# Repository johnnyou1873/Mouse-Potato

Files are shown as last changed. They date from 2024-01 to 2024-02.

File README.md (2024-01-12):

# Mouse-Potato
Micromouse design for AAMC 2024

## Major Components

### Microcontroller
STMicroelectronics STM32F411RETx

### Motors
*2x* CHF-GW12T-N20VA ABHL DC Worm Gear Motor
- Ratio: 42-A
- Voltage: 6V B45
- https://www.aliexpress.us/item/3256801422029348.html
- Requires shortening of the encoder board and resoldering of the cables

### Motor Driver
STMicroelectronics L293DD

### IMU
TDK InvenSense ICM-42688-P

### ToF Sensors
*3x* Adafruit VL6180X Time of Flight Micro-LIDAR Distance Sensor Breakout

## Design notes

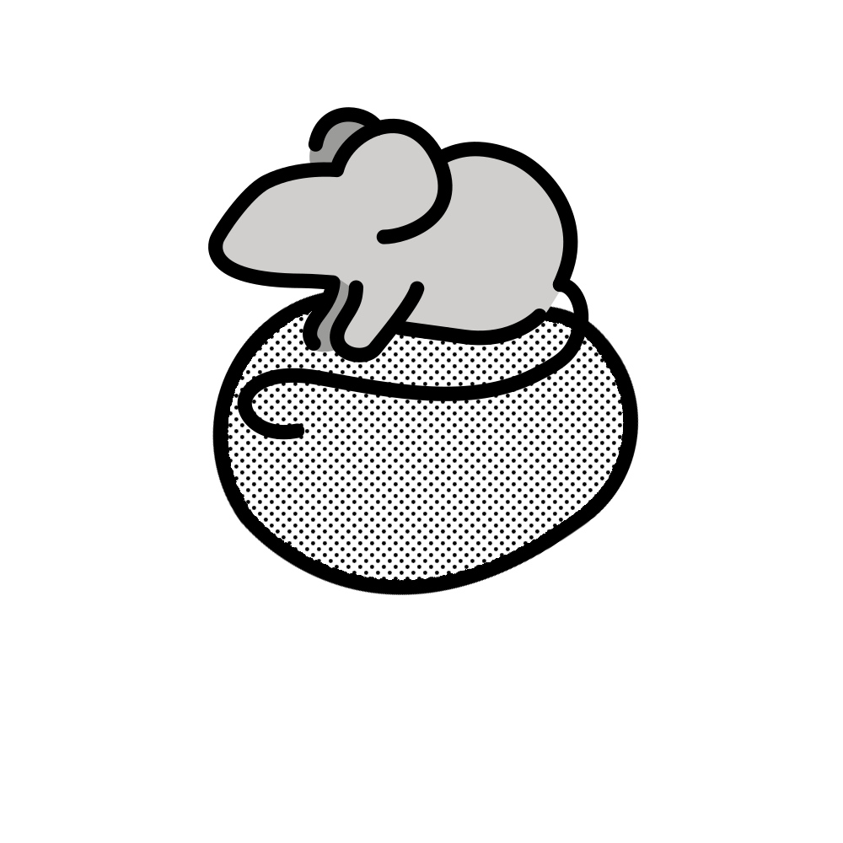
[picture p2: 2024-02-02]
art/mouse_potato.png

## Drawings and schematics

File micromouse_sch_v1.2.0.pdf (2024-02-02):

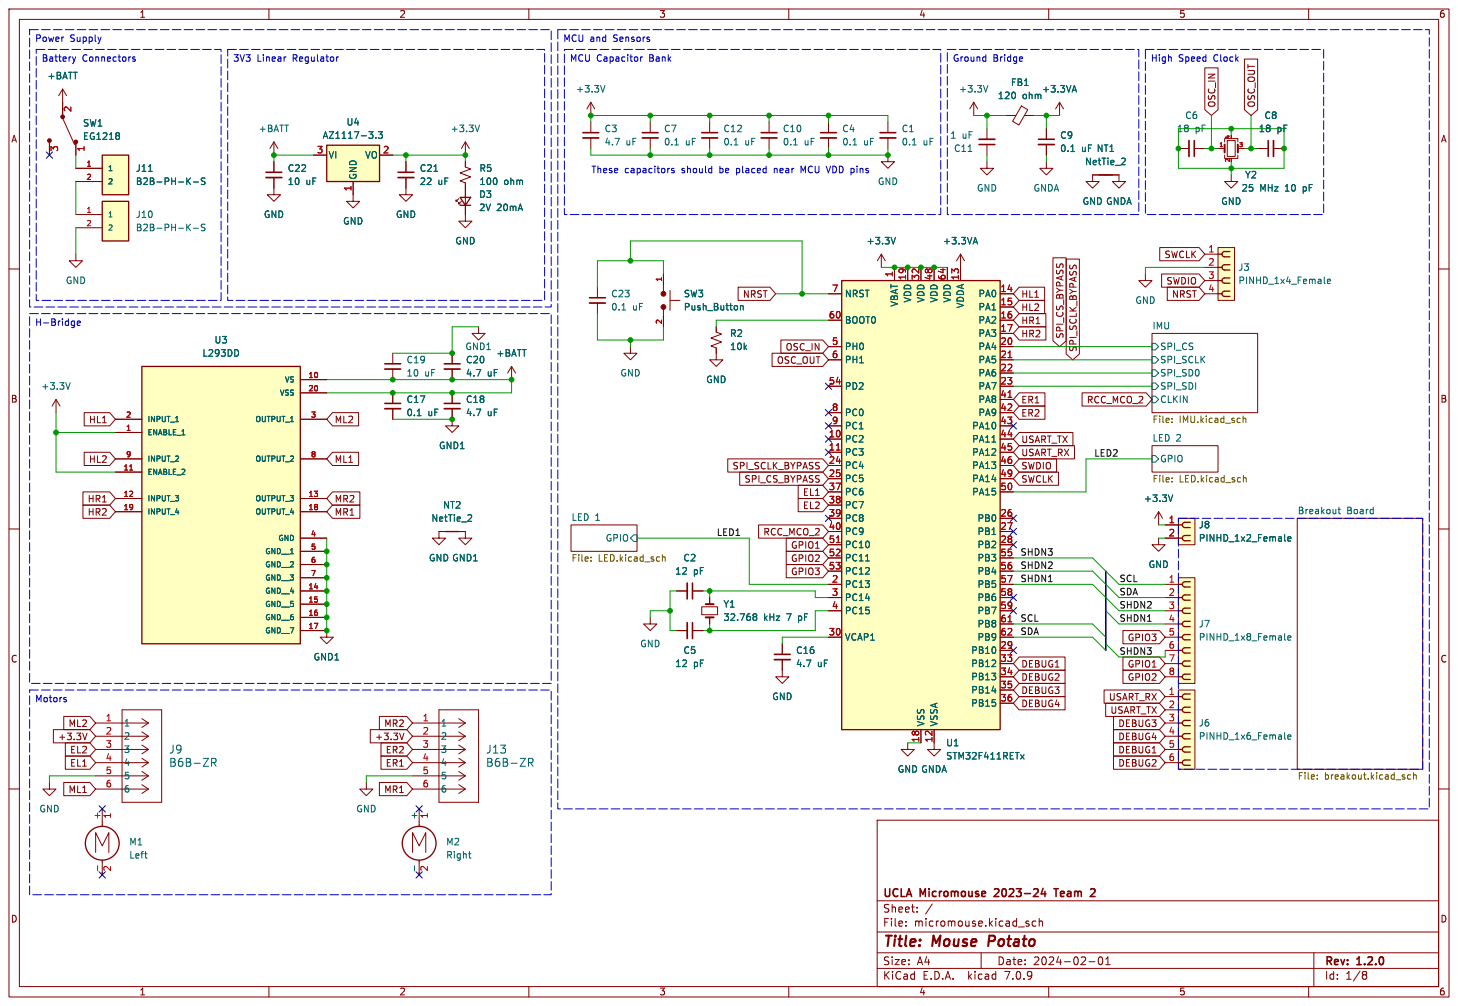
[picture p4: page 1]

1 VO 2 VI 3 U4 AZ1117-3.3 GND GND
+BATT GND

1 VO 2 VI 3 GND GND

1 PC2 10 PC3 11 VSSA 12 VDDA 13 PA0 14 PA1 15 PA2 16 PA3 17 VSS 18 VDD 19 PC13 2 PA4 20 PA5 21 PA6 22 PA7 23 PC4 24 PC5 25 PB0 26 PB1 27 PB2 28 PB10 29 PC14 3 VCAP1 30 VDD 32 PB12 33 PB13 34 PB14 35 PB15 36 PC6 37 PC7 38 PC8 39 PC15 4 PC9 40 PA8 41 PA9 42 PA10 43 PA11 44 PA12 45 PA13 46 VDD 48 PA14 49 PH0 5 PA15 50 PC10 51 PC11 52 PC12 53 PD2 54 PB3 55 PB4 56 PB5 57 PB6 58 PB7 59 PH1 6 BOOT0 60 PB8 61 PB9 62 VDD 64 NRST 7 PC0 8 PC1 9 U1STM32F411RETx GND

1 PC2 10 PC3 11 VSSA 12 VDDA 13 PA0 14 PA1 15 PA2 16 PA3 17 VSS 18 VDD 19 PC13 2 PA4 20 PA5 21 PA6 22 PA7 23 PC4 24 PC5 25 PB0 26 PB1 27 PB2 28 PB10 29 PC14 3 VCAP1 30 VDD 32 PB12 33 PB13 34 PB14 35 PB15 36 PC6 37 PC7 38 PC8 39 PC15 4 PC9 40 PA8 41 PA9 42 PA10 43 PA11 44 PA12 45 PA13 46 VDD 48 PA14 49 PH0 5 PA15 50 PC10 51 PC11 52 PC12 53 PD2 54 PB3 55 PB4 56 PB5 57 PB6 58 PB7 59 PH1 6 BOOT0 60 PB8 61 PB9 62 VDD 64 NRST 7 PC0 8 PC1 9 GND

Id: 1/8 Title: Mouse Potato

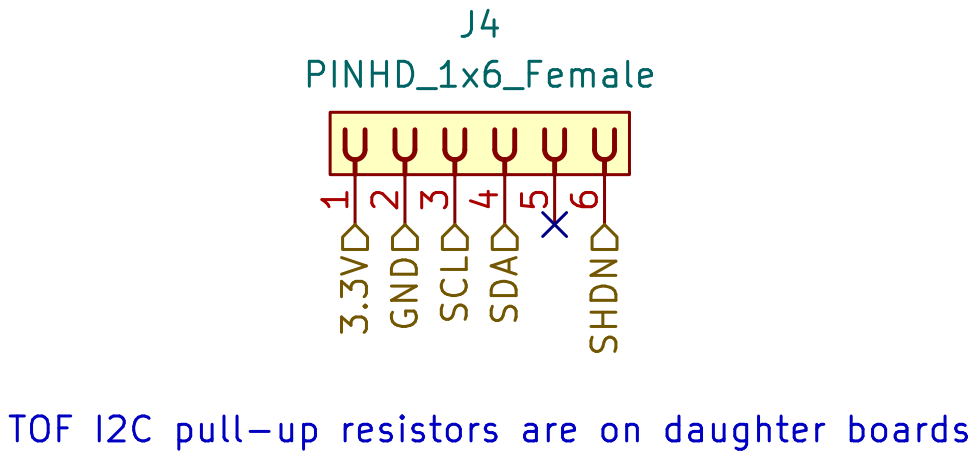
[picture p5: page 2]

Id: 3/8 Title: Mouse Potato

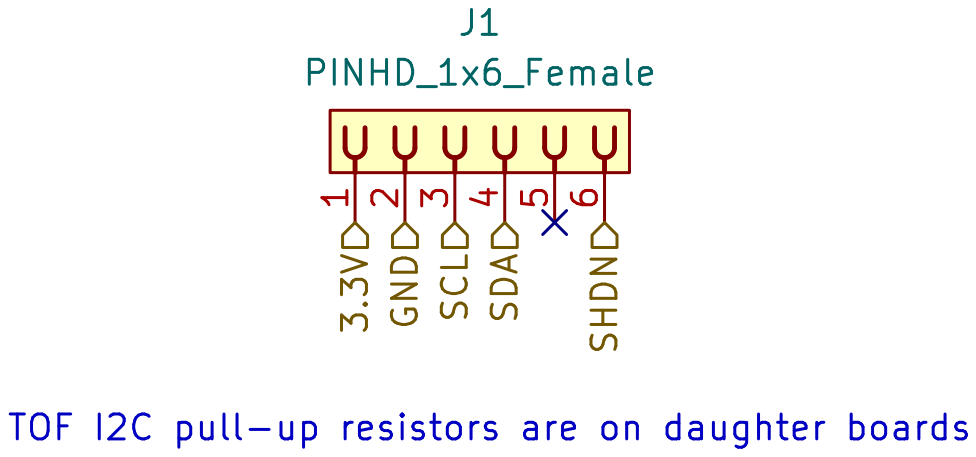
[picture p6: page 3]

Id: 4/8 Title: Mouse Potato

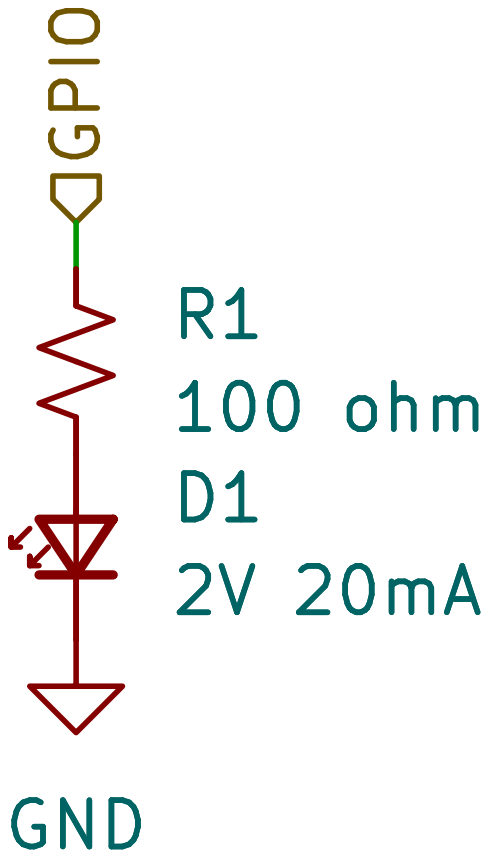
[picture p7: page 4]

Id: 5/8 Title: Mouse Potato

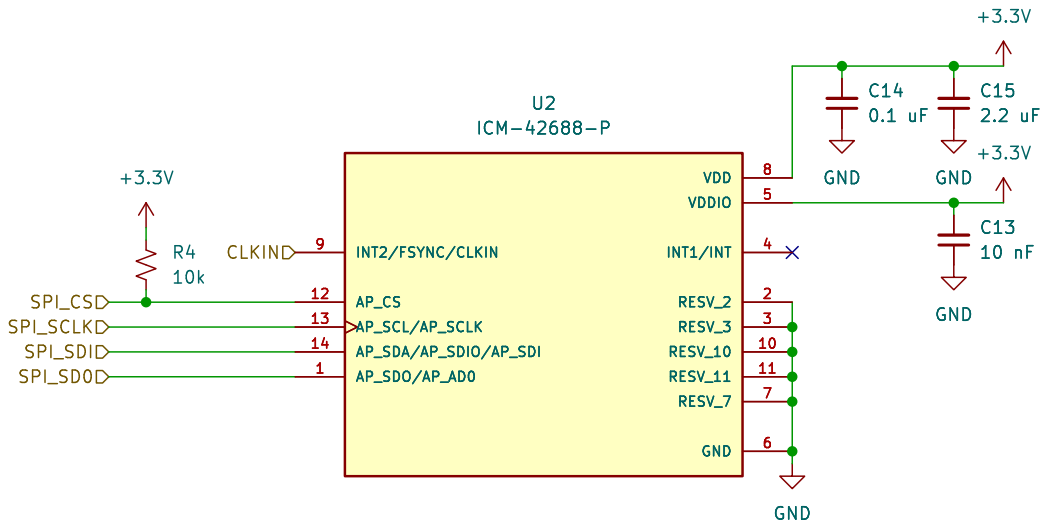
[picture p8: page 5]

Id: 6/8 Title: Mouse Potato

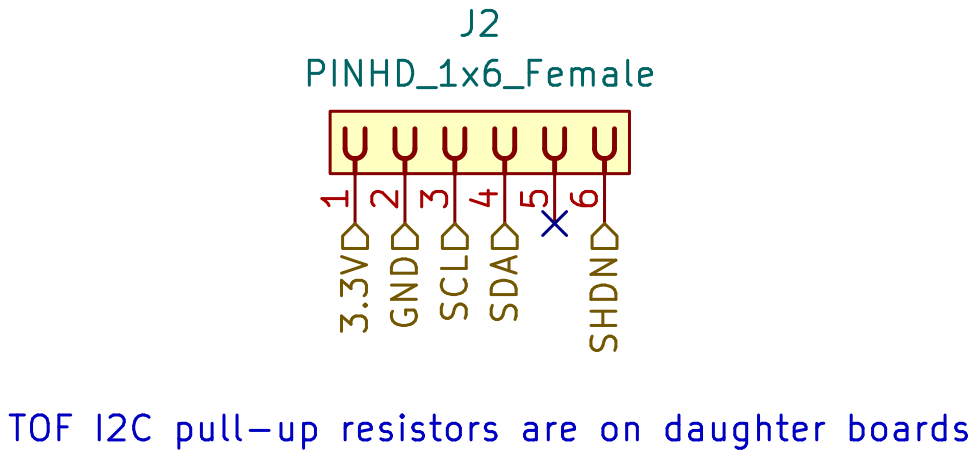
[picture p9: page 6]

Id: 7/8 Title: Mouse Potato

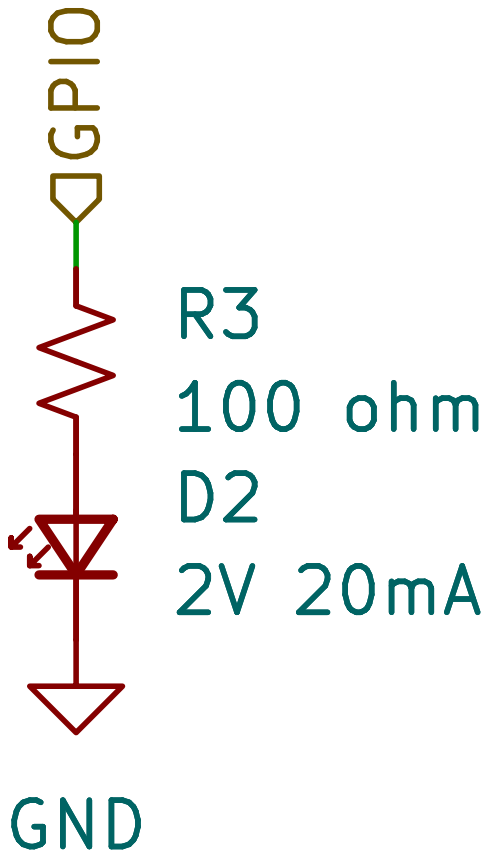
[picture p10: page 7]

Id: 8/8 Title: Mouse Potato

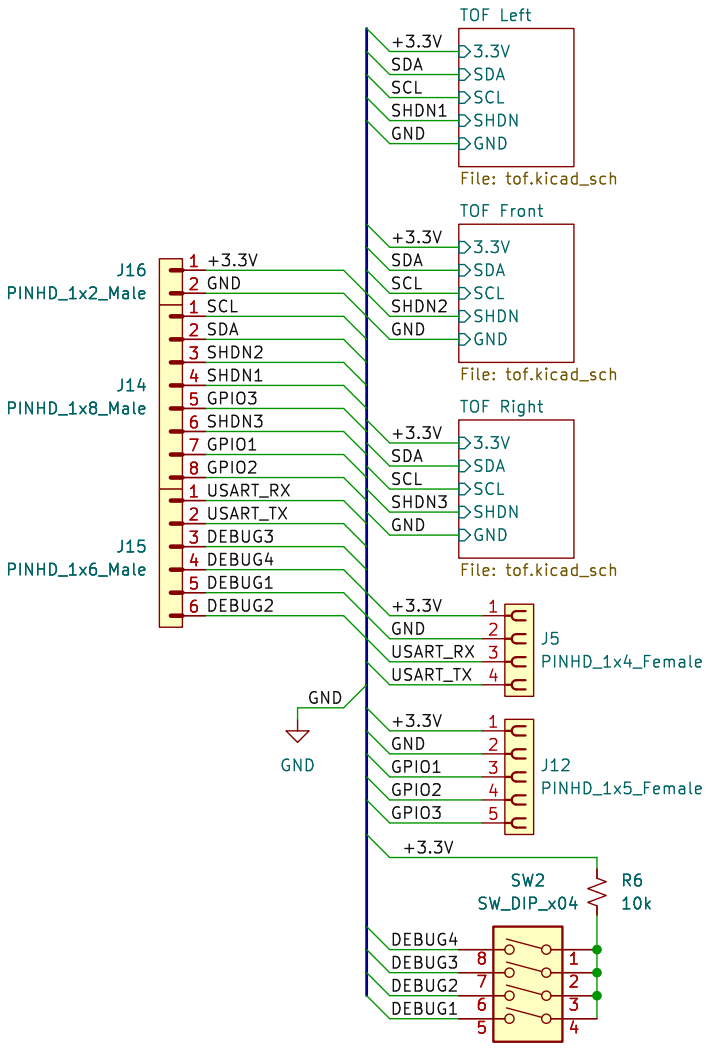
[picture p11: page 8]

TOF Left File: tof.kicad_sch 1234
TOF Right File: tof.kicad_sch SCL SDA
TOF Front File: tof.kicad_sch SCL SDA
SHDN2 +3.3V

Id: 11/8 Title: Mouse Potato

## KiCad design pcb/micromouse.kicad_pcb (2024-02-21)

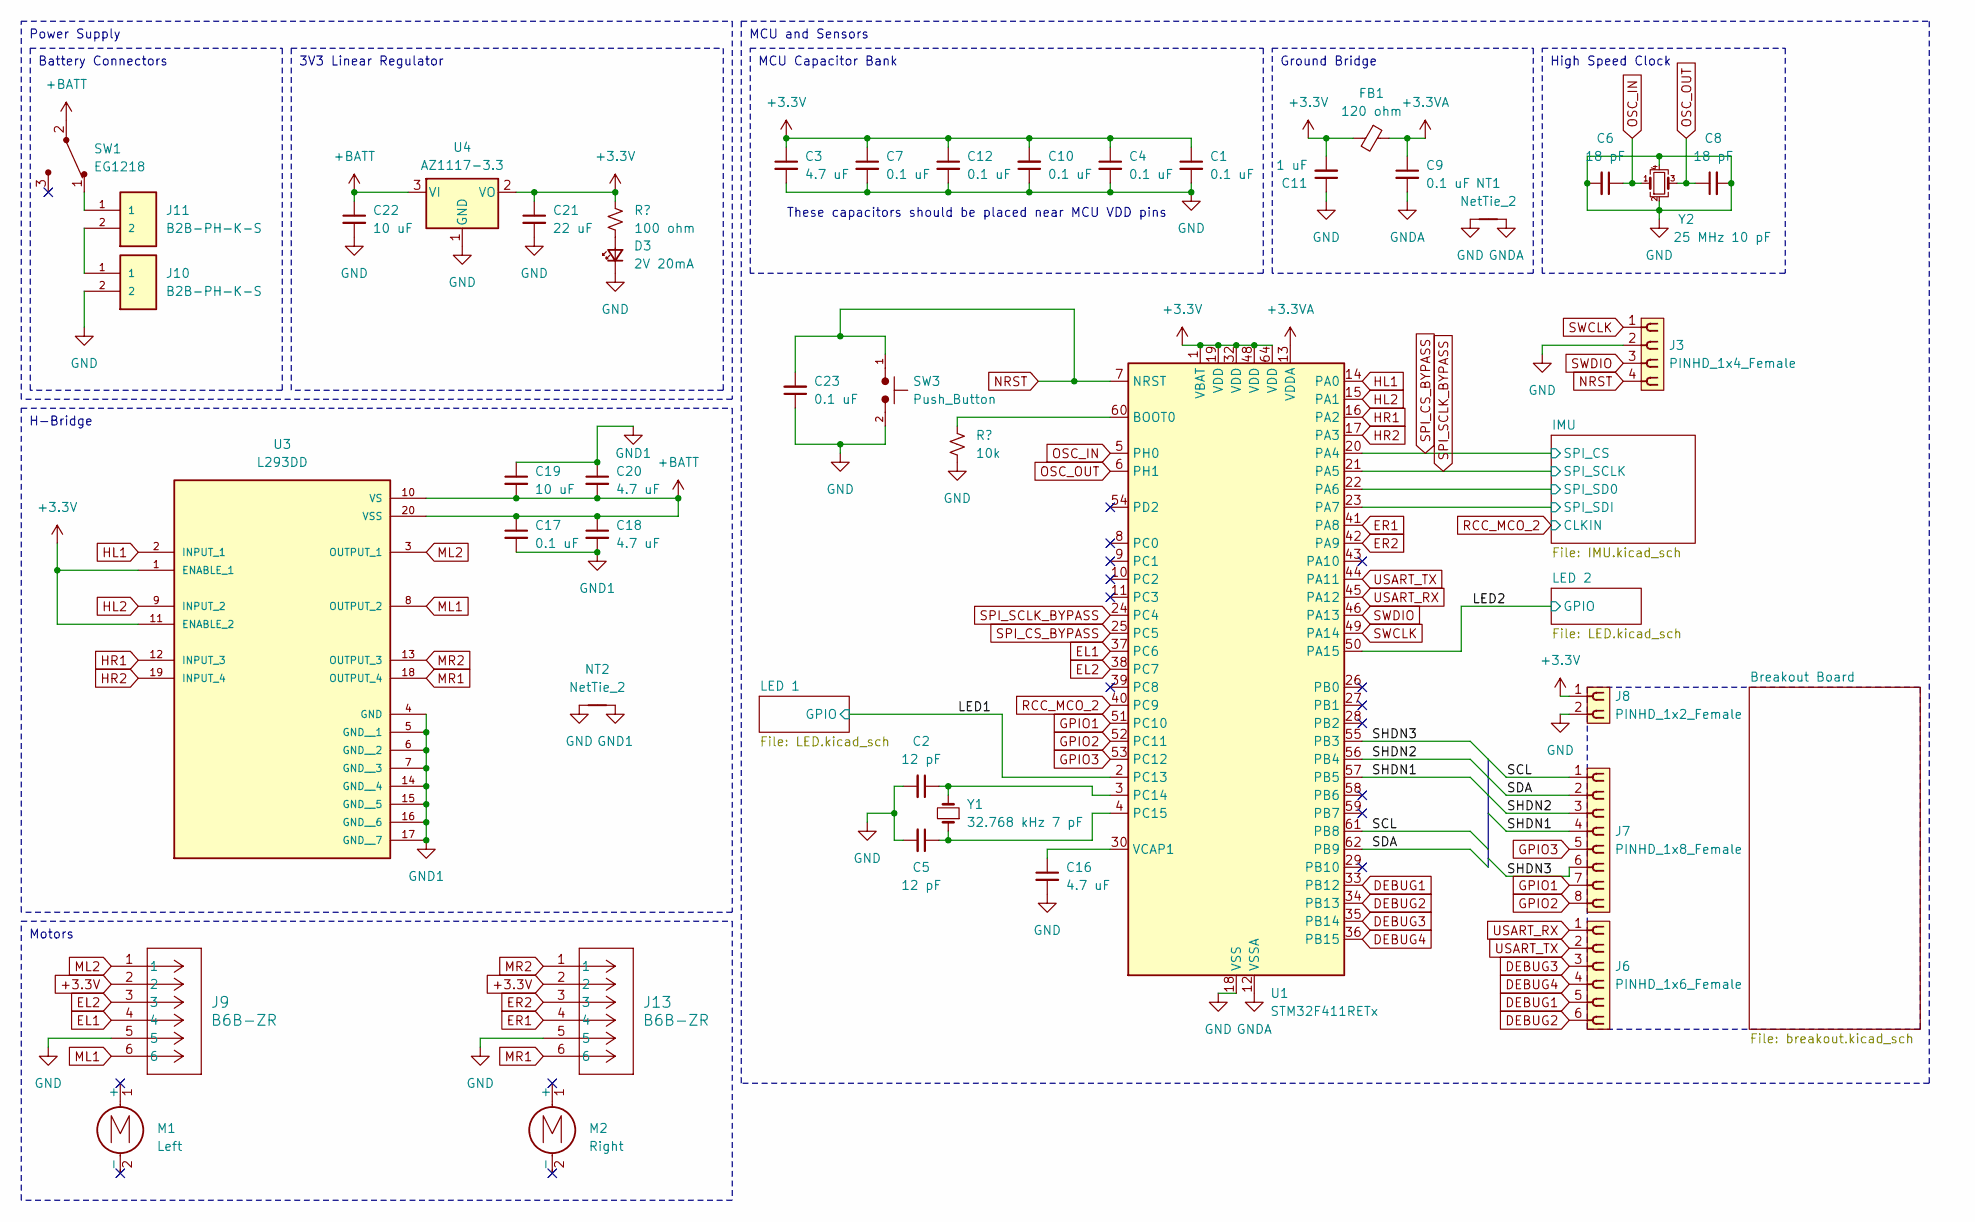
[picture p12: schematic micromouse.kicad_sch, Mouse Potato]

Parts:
C1, C4, C7, C9, C10, C12, C17, C23: 0.1 uF; C_0603_1608Metric
C2, C5: 12 pF; C_0603_1608Metric
C3, C16, C18, C20: 4.7 uF; C_0603_1608Metric
C6, C8: 18 pF; C_0603_1608Metric
C11: 1 uF; C_0603_1608Metric
C19, C22: 10 uF; C_0603_1608Metric
C21: 22 uF; C_0603_1608Metric
D3: 2V 20mA; LED_0603_1608Metric
FB1: 120 ohm; L_0603_1608Metric
J3: PINHD_1x4_Female; PinSocket_1x04_P2.54mm_Vertical
J6: PINHD_1x6_Female; PinSocket_2x03_P2.54mm_Vertical
J7: PINHD_1x8_Female; PinSocket_2x04_P2.54mm_Vertical
J8: PINHD_1x2_Female; PinSocket_1x02_P2.54mm_Vertical
J9, J13: B6B-ZR; CONN_B6B-ZR_JST
J10, J11: B2B-PH-K-S; JST_B2B-PH-K-S_LF__SN_; PARTREV N/A; DIGI-KEY_PART_NUMBER 455-1704-ND
M1: Left; MM_Motor_Left
M2: Right; MM_Motor_Right
NT1, NT2: NetTie_2; NetTie-2_SMD_Pad0.5mm
R2: 10k; R_0603_1608Metric
R5: 100 ohm; R_0603_1608Metric
SW1: EG1218; Switch_Slide_11.6x4mm_EG1218; MPN EG1218; Digi-Key_PN EG1903-ND
SW3: Push_Button; SolderJumper-2_P1.3mm_Open_Pad1.0x1.5mm
U1: STM32F411RETx; LQFP-64_10x10mm_P0.5mm
U3: L293DD; SOIC127P1032X265-20N; PARTREV N/A
U4: AZ1117-3.3; SOT-223-3_TabPin2
Y1: 32.768 kHz 7 pF; XTAL_SC32S-7PF20PPM_EPS
Y2: 25 MHz 10 pF; XTAL4P_RH100-25.000-10-F-3030-EXT-TR_RAL

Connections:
+3.3V: C1.1, C3.1, C4.1, C7.1, C10.2, C11.2, C12.1, C21.1, FB1.2, J8.1, J9.2, J13.2, R5.2, U1.1 (VBAT), U1.19 (VDD), U1.32 (VDD), U1.48 (VDD), U1.64 (VDD), U3.1 (ENABLE_1), U3.11 (ENABLE_2), U4.2 (VO); also elsewhere on the board
+3.3VA: C9.1, FB1.1, U1.13 (VDDA)
+BATT: C17.1, C18.1, C19.2, C20.2, C22.1, SW1.2, U3.10 (VS), U3.20 (VSS), U4.3 (VI)
/IMU/SPI_SD0: U1.22 (PA6); also elsewhere on the board
/IMU/SPI_SDI: U1.23 (PA7); also elsewhere on the board
/LED1: U1.2 (PC13); also elsewhere on the board
/LED2: U1.50 (PA15); also elsewhere on the board
/SCL: J7.1, U1.61 (PB8)
/SDA: J7.2, U1.62 (PB9)
/SHDN1: J7.4, U1.57 (PB5)
/SHDN2: J7.3, U1.56 (PB4)
/SHDN3: J7.6, U1.55 (PB3)
DEBUG1: J6.5, U1.33 (PB12)
DEBUG2: J6.6, U1.34 (PB13)
DEBUG3: J6.3, U1.35 (PB14)
DEBUG4: J6.4, U1.36 (PB15)
EL1: J9.4, U1.37 (PC6)
EL2: J9.3, U1.38 (PC7)
ER1: J13.4, U1.41 (PA8)
ER2: J13.3, U1.42 (PA9)
GND1: C17.2, C18.2, C19.1, C20.1, NT2.2, U3.4 (GND), U3.5 (GND__1), U3.6 (GND__2), U3.7 (GND__3), U3.14 (GND__4), U3.15 (GND__5), U3.16 (GND__6), U3.17 (GND__7)
GNDA: C9.2, NT1.2, U1.12 (VSSA)
GPIO1: J7.7, U1.51 (PC10)
GPIO2: J7.8, U1.52 (PC11)
GPIO3: J7.5, U1.53 (PC12)
HL1: U1.14 (PA0), U3.2 (INPUT_1)
HL2: U1.15 (PA1), U3.9 (INPUT_2)
HR1: U1.16 (PA2), U3.12 (INPUT_3)
HR2: U1.17 (PA3), U3.19 (INPUT_4)
ML1: J9.6, U3.8 (OUTPUT_2)
ML2: J9.1, U3.3 (OUTPUT_1)
MR1: J13.6, U3.18 (OUTPUT_4)
MR2: J13.1, U3.13 (OUTPUT_3)
NRST: C23.2, J3.4, SW3.1, U1.7 (NRST)
unnamed: D3.2 (A), R5.1
unnamed: J10.1, J11.2
unnamed: J11.1, SW1.1
unnamed: C2.1, U1.3 (PC14), Y1.2
unnamed: C5.1, U1.4 (PC15), Y1.1
unnamed: C16.1, U1.30 (VCAP1)
OSC_IN: C6.1, U1.5 (PH0), Y2.1
OSC_OUT: C8.1, U1.6 (PH1), Y2.3
RCC_MCO_2: U1.40 (PC9); also elsewhere on the board
SPI_CS_BYPASS: U1.20 (PA4), U1.25 (PC5); also elsewhere on the board
SPI_SCLK_BYPASS: U1.21 (PA5), U1.24 (PC4); also elsewhere on the board
SWCLK: J3.1, U1.49 (PA14)
SWDIO: J3.3, U1.46 (PA13)
USART_RX: J6.1, U1.45 (PA12)
USART_TX: J6.2, U1.44 (PA11)

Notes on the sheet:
H-Bridge
3V3 Linear Regulator
Ground Bridge
MCU and Sensors
Motors
MCU Capacitor Bank
Power Supply
High Speed Clock
Battery Connectors
These capacitors should be placed near MCU VDD pins

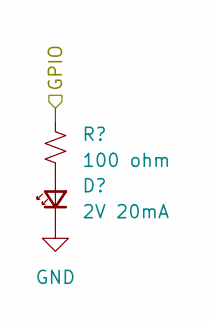
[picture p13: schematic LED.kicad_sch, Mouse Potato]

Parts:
D1: 2V 20mA; LED_0603_1608Metric
R1: 100 ohm; R_0603_1608Metric

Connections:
/LED1: R1.2; also elsewhere on the board
unnamed: D1.2 (A), R1.1

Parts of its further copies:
D2: 2V 20mA; LED_0603_1608Metric
R3: 100 ohm; R_0603_1608Metric

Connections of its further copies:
/LED2: R3.2; also elsewhere on the board
unnamed: D2.2 (A), R3.1

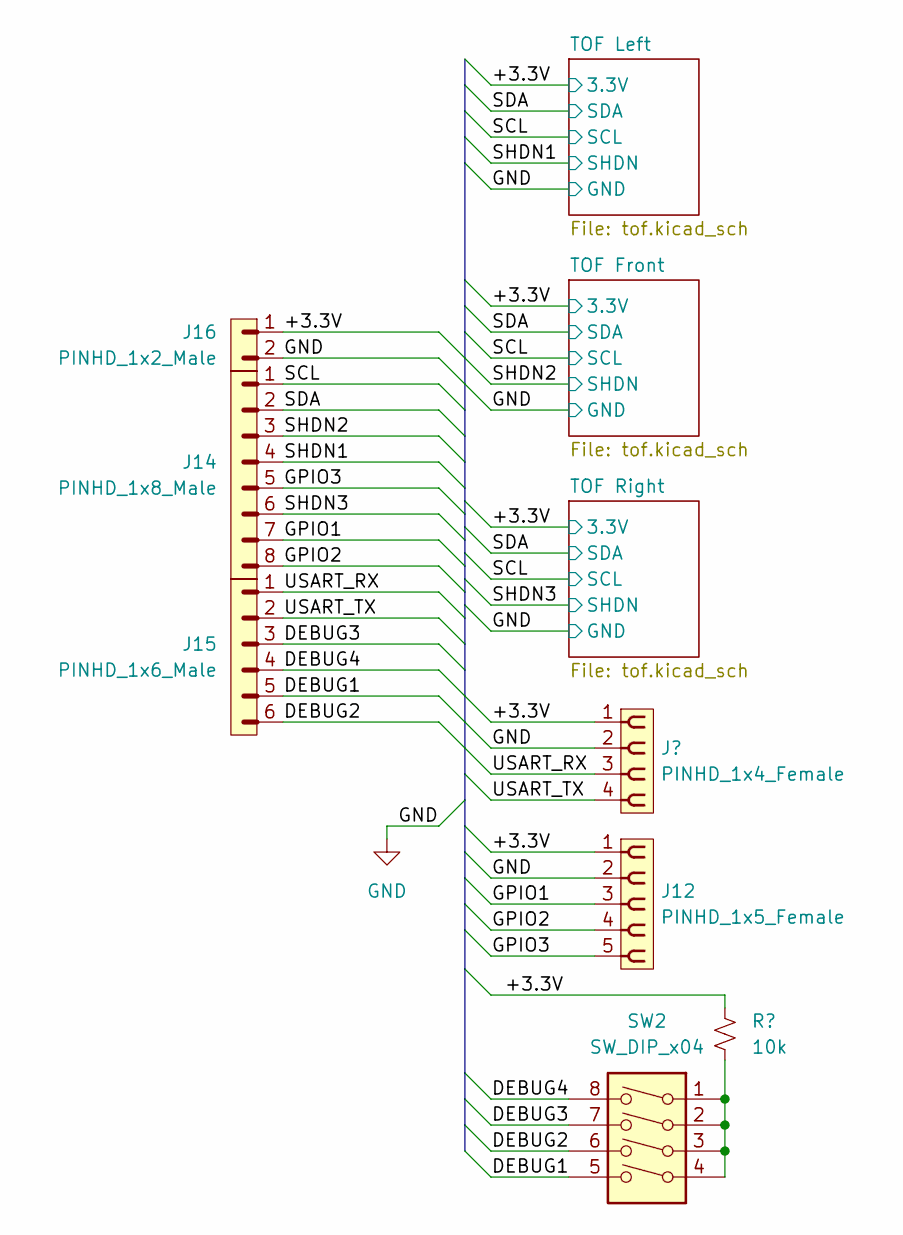
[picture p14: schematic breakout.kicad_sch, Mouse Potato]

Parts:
J5: PINHD_1x4_Female; PinSocket_1x04_P2.54mm_Vertical
J12: PINHD_1x5_Female; PinSocket_1x05_P2.54mm_Vertical
J14: PINHD_1x8_Male; PinHeader_2x04_P2.54mm_Vertical
J15: PINHD_1x6_Male; PinHeader_2x03_P2.54mm_Vertical
J16: PINHD_1x2_Male; PinHeader_1x02_P2.54mm_Vertical
R2: 10k; R_0603_1608Metric
SW2: SW_DIP_x04; 218-4LPST

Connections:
/Breakout Board/DEBUG1: J15.5, SW2.5
/Breakout Board/DEBUG2: J15.6, SW2.6
/Breakout Board/DEBUG3: J15.3, SW2.7
/Breakout Board/DEBUG4: J15.4, SW2.8
/Breakout Board/GPIO1: J12.3, J14.7
/Breakout Board/GPIO2: J12.4, J14.8
/Breakout Board/GPIO3: J12.5, J14.5
/Breakout Board/SCL: J14.1; also elsewhere on the board
/Breakout Board/SDA: J14.2; also elsewhere on the board
/Breakout Board/SHDN1: J14.4; also elsewhere on the board
/Breakout Board/SHDN2: J14.3; also elsewhere on the board
/Breakout Board/SHDN3: J14.6; also elsewhere on the board
/Breakout Board/USART_RX: J5.3, J15.1
/Breakout Board/USART_TX: J5.4, J15.2

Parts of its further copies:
R6: 10k; R_0603_1608Metric

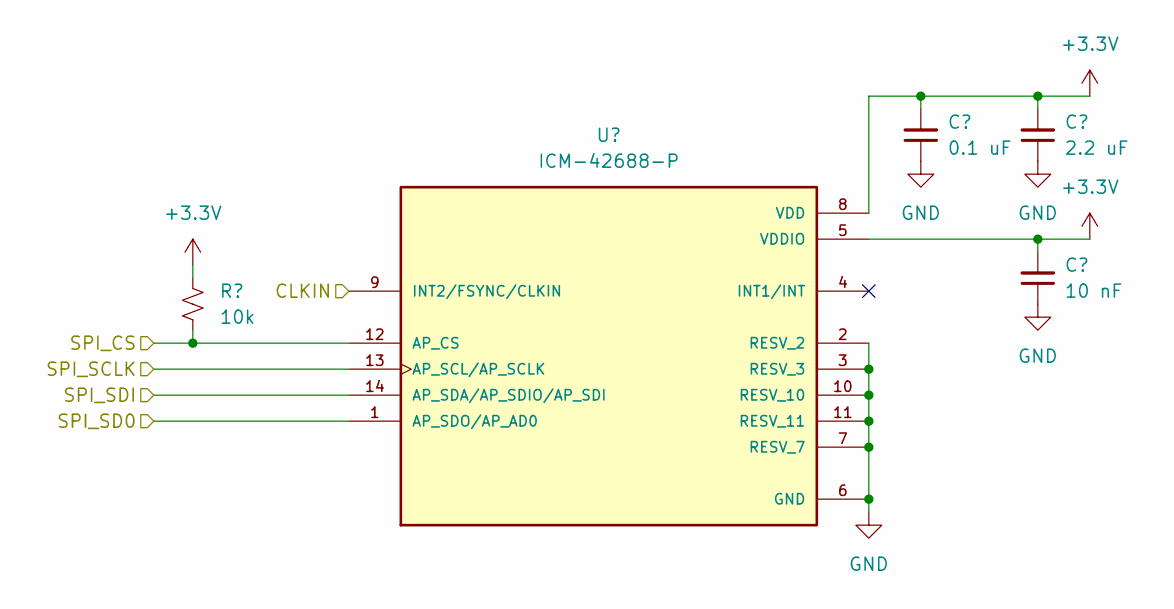
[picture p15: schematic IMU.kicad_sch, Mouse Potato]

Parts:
C13: 10 nF; C_0603_1608Metric
C14: 0.1 uF; C_0603_1608Metric
C15: 2.2 uF; C_0603_1608Metric
R4: 10k; R_0603_1608Metric
U2: ICM-42688-P; PQFN50P300X250X97-14N; PARTREV 1.2

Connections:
+3.3V: C13.2, C14.2, C15.2, R4.2, U2.5 (VDDIO), U2.8 (VDD); also elsewhere on the board
/IMU/SPI_SD0: U2.1 (AP_SDO/AP_AD0); also elsewhere on the board
/IMU/SPI_SDI: U2.14 (AP_SDA/AP_SDIO/AP_SDI); also elsewhere on the board
RCC_MCO_2: U2.9 (INT2/FSYNC/CLKIN); also elsewhere on the board
SPI_CS_BYPASS: R4.1, U2.12 (AP_CS); also elsewhere on the board
SPI_SCLK_BYPASS: U2.13 (AP_SCL/AP_SCLK); also elsewhere on the board

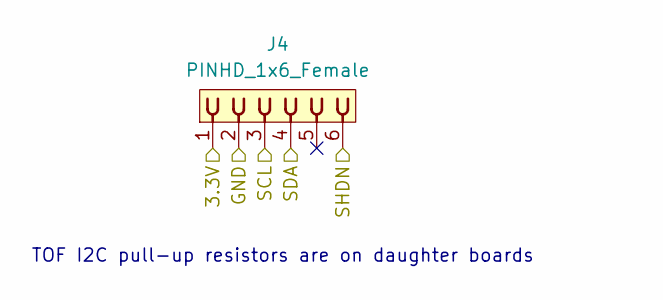
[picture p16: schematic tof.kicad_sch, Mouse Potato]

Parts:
J4: PINHD_1x6_Female; PinSocket_1x06_P2.54mm_Vertical

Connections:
/Breakout Board/SCL: J4.3; also elsewhere on the board
/Breakout Board/SDA: J4.4; also elsewhere on the board
/Breakout Board/SHDN3: J4.6; also elsewhere on the board

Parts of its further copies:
J1, J2: PINHD_1x6_Female; PinSocket_1x06_P2.54mm_Vertical

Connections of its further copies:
/Breakout Board/SCL: J1.3, J2.3; also elsewhere on the board
/Breakout Board/SDA: J1.4, J2.4; also elsewhere on the board
/Breakout Board/SHDN1: J1.6; also elsewhere on the board
/Breakout Board/SHDN2: J2.6; also elsewhere on the board

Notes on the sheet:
TOF I2C pull-up resistors are on daughter boards

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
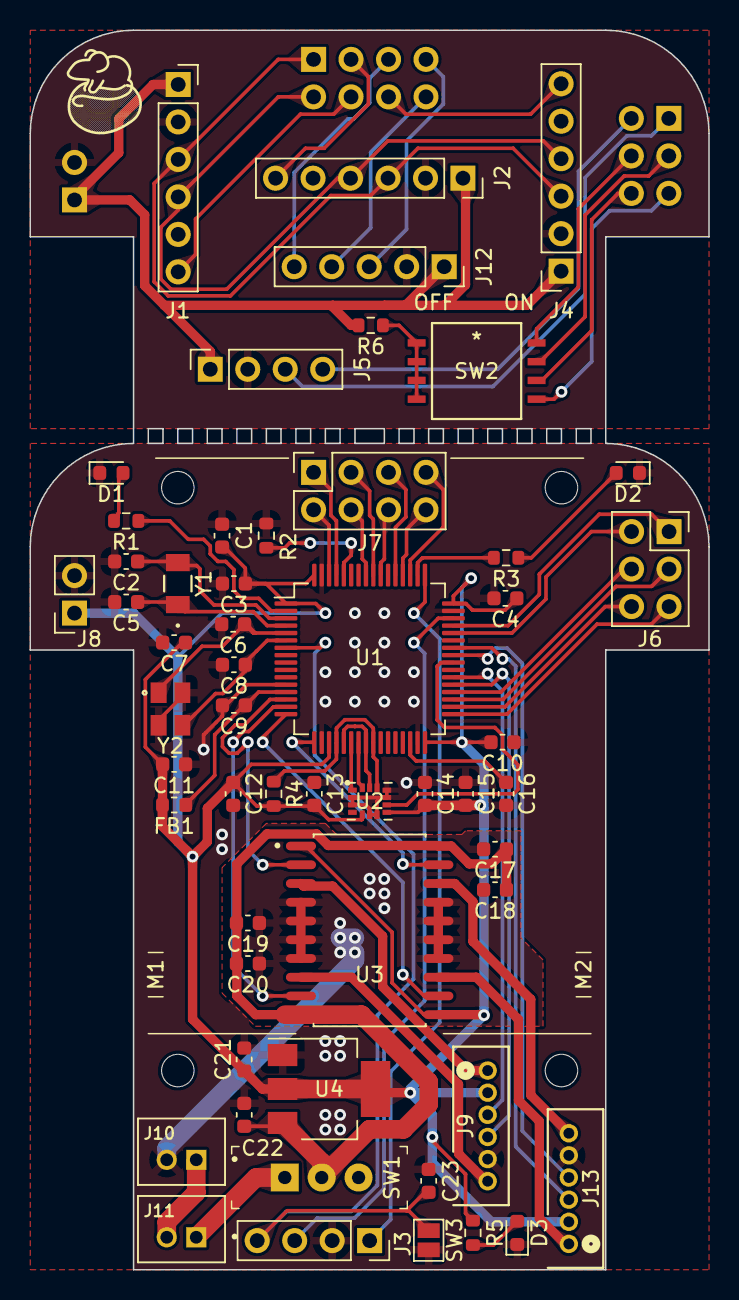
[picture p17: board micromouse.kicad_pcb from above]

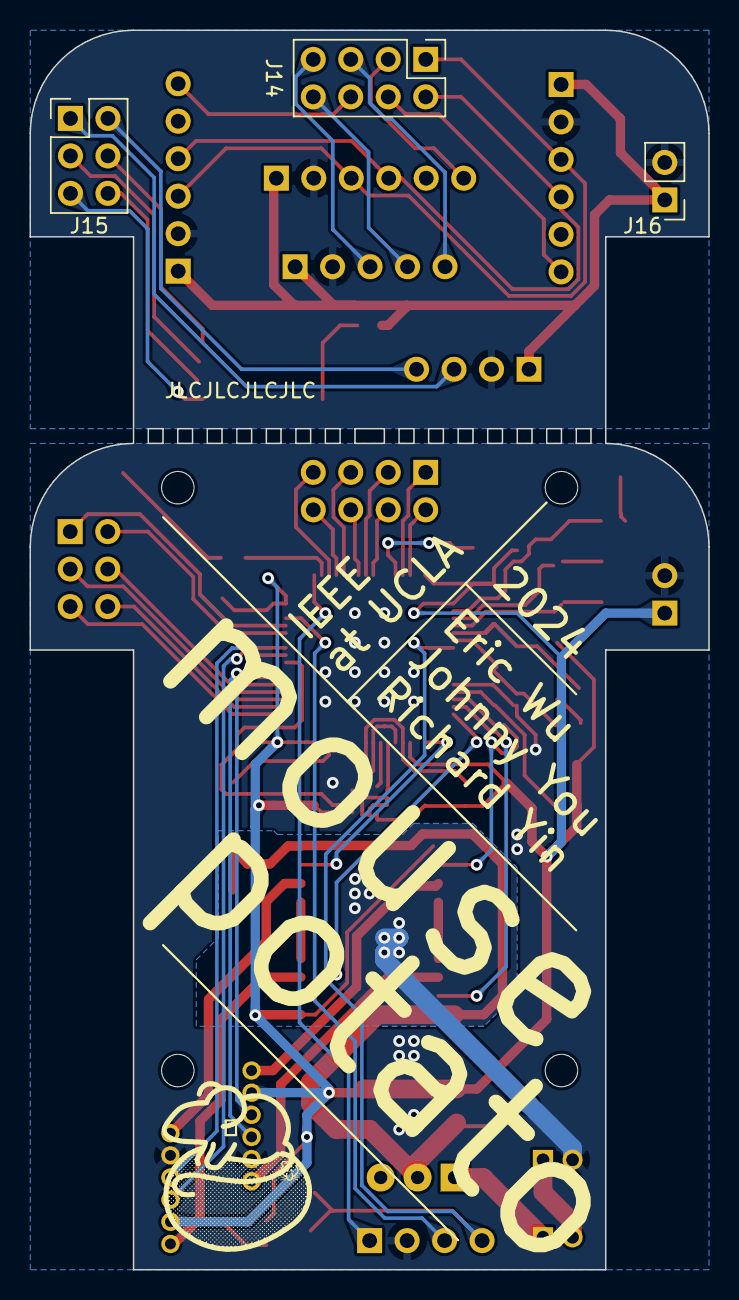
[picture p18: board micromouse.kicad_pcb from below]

Board: 2 copper layers, 46.0 x 84.0 mm, 62 parts (4 on the bottom side), 69 nets.

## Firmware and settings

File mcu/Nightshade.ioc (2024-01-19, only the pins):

Mcu.UserName=STM32F411RETx
PA0-WKUP.Signal=S_TIM5_CH1
PA1.Signal=S_TIM5_CH2
PA10.Signal=GPIO_Output
PA11.Signal=USART6_TX
PA12.Signal=USART6_RX
PA13.Signal=SYS_JTMS-SWDIO
PA14.Signal=SYS_JTCK-SWCLK
PA2.Signal=S_TIM5_CH3
PA3.Signal=S_TIM5_CH4
PA4.Signal=SPI1_NSS
PA5.Signal=SPI1_SCK
PA6.Signal=SPI1_MISO
PA7.Signal=SPI1_MOSI
PA8.Signal=S_TIM1_CH1
PA9.Signal=S_TIM1_CH2
PB10.Signal=GPIO_Output
PB12.Signal=GPIO_Input
PB13.Signal=GPIO_Input
PB14.Signal=GPIO_Input
PB15.Signal=GPIO_Input
PB3.Signal=GPIO_Output
PB4.Signal=GPIO_Output
PB5.Signal=GPIO_Output
PB8.Signal=I2C1_SCL
PB9.Signal=I2C1_SDA
PC10.Signal=SPI3_SCK
PC11.Signal=SPI3_MISO
PC12.Signal=SPI3_MOSI
PC13-ANTI_TAMP.Signal=GPIO_Output
PC14-OSC32_IN.Signal=RCC_OSC32_IN
PC15-OSC32_OUT.Signal=RCC_OSC32_OUT
PC6.Signal=S_TIM3_CH1
PC7.Signal=S_TIM3_CH2
PC9.Signal=RCC_MCO_2

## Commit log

2023-12-24 Create pcb
2024-01-17 Fixed folder structure
    [3V3_linear_regulator.kicad_sch, IMU.kicad_sch, IR_Sensor.kicad_sch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]
2024-01-19 added "switch" (jumper)
    [micromouse.kicad_pcb, micromouse.kicad_sch]
2024-02-01 added reset jumper to PCB
    [micromouse.kicad_pcb, micromouse.kicad_sch]
2024-02-01 update board art (still need to put pictures, though)
    [micromouse.kicad_pcb]
2024-02-02 added board art
    [micromouse.kicad_pcb]
2024-02-02 regenerated schematic pdf
    [IMU.kicad_sch, LED.kicad_sch, breakout.kicad_sch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]
2024-02-02 Added gerbers and drill files
    [micromouse-B_Cu.gbr, micromouse-B_Mask.gbr, micromouse-B_Paste.gbr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]
2024-02-02 reformatted gerbers
    [micromouse-B_Cu.gbr, micromouse-B_Mask.gbr, micromouse-B_Paste.gbr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]
2024-02-04 Updated board from MM lead feedback
    [micromouse.kicad_pcb]
2024-02-04 Updated gerbers
    [micromouse-B_Cu.gbr, micromouse-B_Mask.gbr, micromouse-B_Paste.gbr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]
2024-02-04 Fixed mousebites
    [micromouse-B_Cu.gbr, micromouse-B_Mask.gbr, micromouse-B_Paste.gbr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]
2024-02-06 Fixed PCB silkscreen, teardrops
    [breakout.kicad_sch, micromouse.kicad_pcb, micromouse.kicad_sch]
2024-02-08 Regenerate Gerbers
    [micromouse-B_Cu.gbr, micromouse-B_Mask.gbr, micromouse-B_Paste.gbr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]
2024-02-21 Removed redundant trace segment
    [micromouse.kicad_pcb]
